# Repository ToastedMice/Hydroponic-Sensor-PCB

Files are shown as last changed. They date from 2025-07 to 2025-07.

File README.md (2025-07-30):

# Hydroponic-Sensor-PCB

A custom PCB designed for managing a smart hydroponic system. It will definitly need some modification as my use case is so specifc. It integrates components needed to automate water and nutrient delivery using peristaltic pumps and sensor feedback. I chose to use cheap sensors rather than good ones so that might need changing too.

## Features

- **5x N-Channel MOSFETs**  
  For switching 0-36v peristaltic pumps, I used NRF20L01's but it would probably be better for Rpi to get some logic level mosfets.

- **Sensor Support**  
  Has a port for pH sensor,EC, i2C USB port for a TSL2591 light sensor.

- **Microcontroller-Friendly**  
  Headers make it easy to connect additional i2c or 5v devices.

- **Compact Form Factor**  
  Layout for enclosure mounting and wire management. pH, EC, Battery could go inside a case

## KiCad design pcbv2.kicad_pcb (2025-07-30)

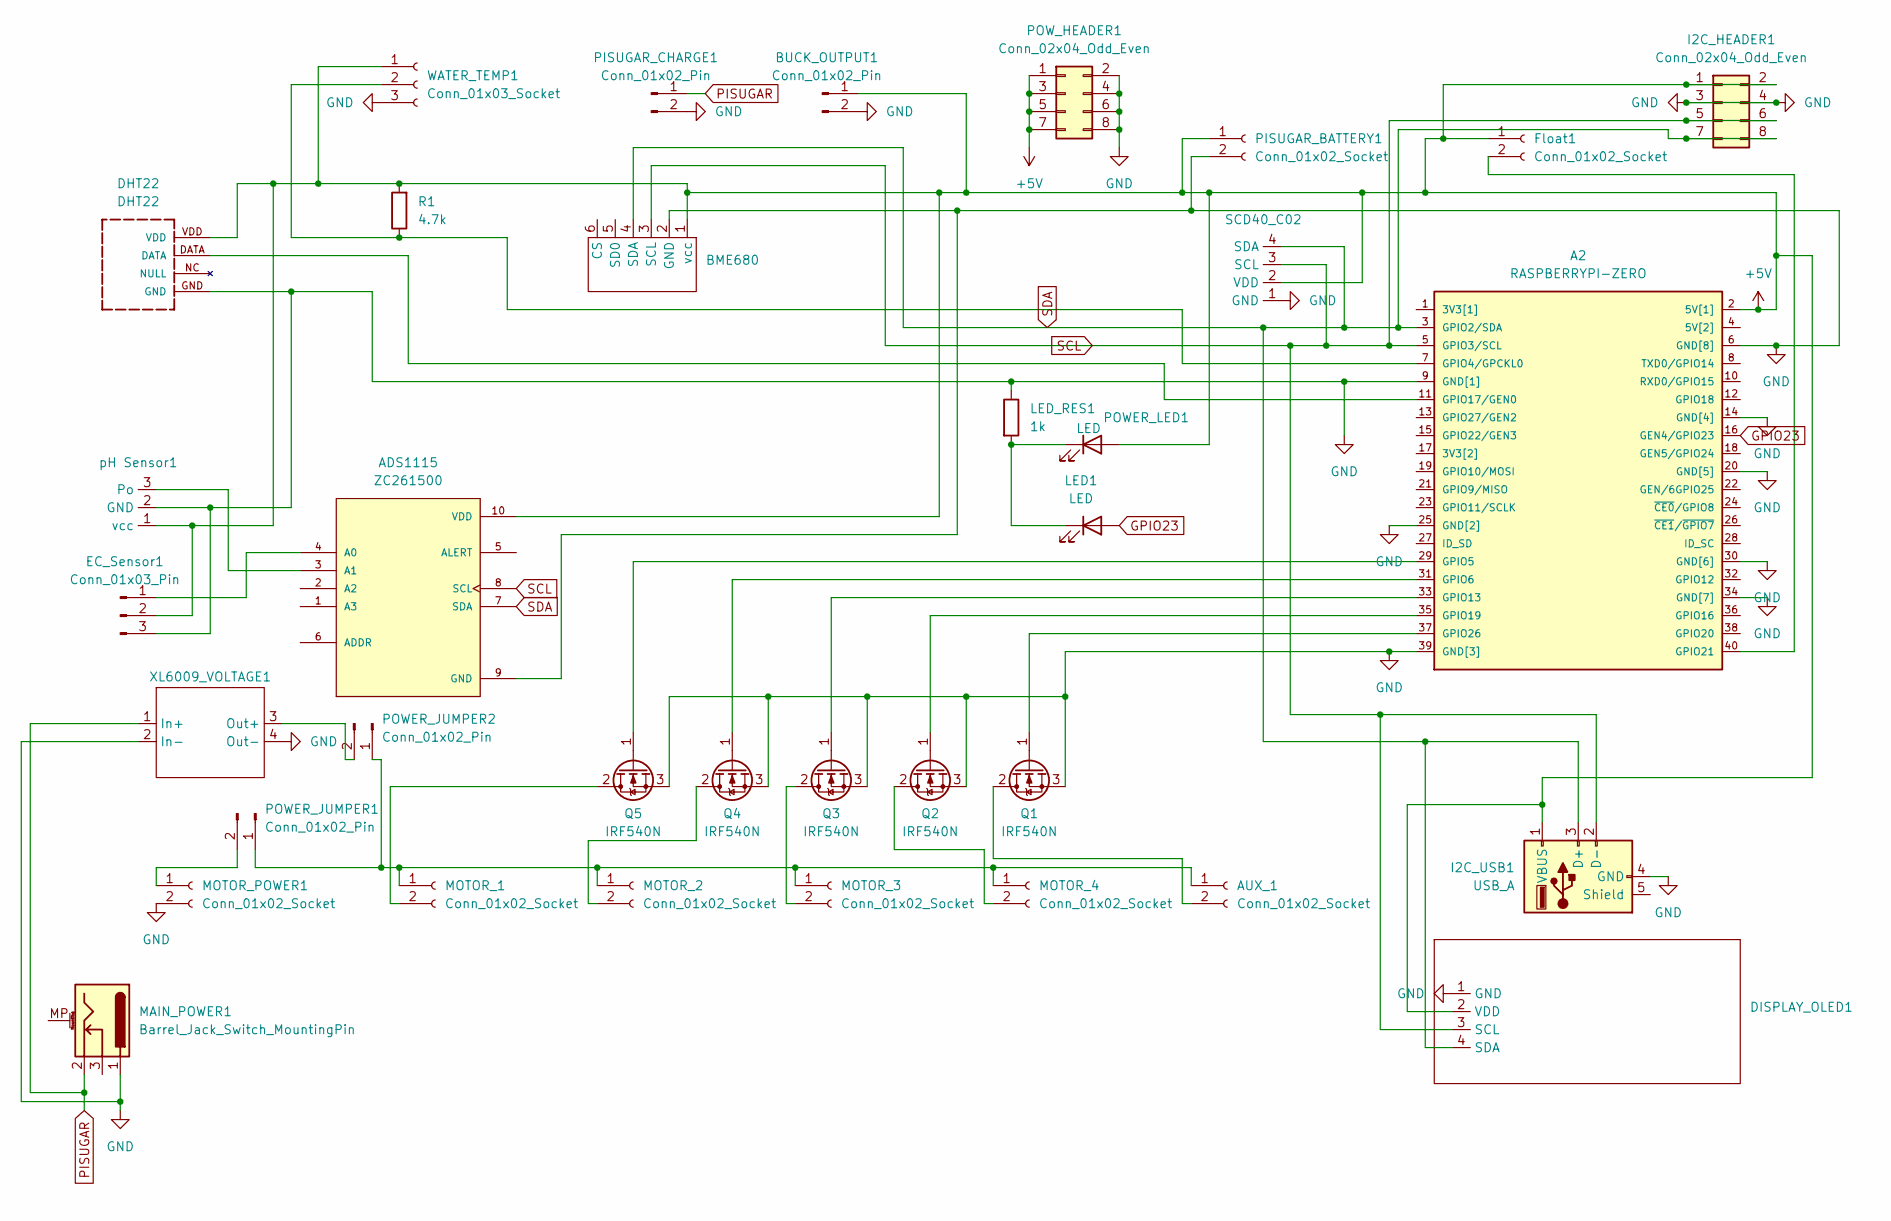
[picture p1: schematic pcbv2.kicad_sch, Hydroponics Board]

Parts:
A2: RASPBERRYPI-ZERO; RASPBERRYPI-ZERO_RPI-ZERO
ADS1115: ZC261500; MODULE_ZC261500; PARTREV NA
AUX_1: Conn_01x02_Socket; JST_XH_S2B-XH-A-1_1x02_P2.50mm_Horizontal
BME680: PinSocket_1x06_P2.54mm_Vertical
BUCK_OUTPUT1: Conn_01x02_Pin; JST_XH_S2B-XH-A-1_1x02_P2.50mm_Horizontal
DHT22: DHT22
DISPLAY_OLED1: JST_XH_S4B-XH-A-1_1x04_P2.50mm_Horizontal
EC_Sensor1: Conn_01x03_Pin; JST_XH_S3B-XH-A-1_1x03_P2.50mm_Horizontal
Float1: Conn_01x02_Socket; JST_XH_S2B-XH-A-1_1x02_P2.50mm_Horizontal
I2C_HEADER1: Conn_02x04_Odd_Even; PinHeader_2x04_P2.54mm_Vertical
I2C_USB1: USB_A; USB_A_Kycon_KUSBX-AS1N-B_Horizontal
LED1: LED; LED_D3.0mm
LED_RES1: 1k; R_Axial_DIN0207_L6.3mm_D2.5mm_P10.16mm_Horizontal
MAIN_POWER1: Barrel_Jack_Switch_MountingPin; BarrelJack_Horizontal
MOTOR_1, MOTOR_2, MOTOR_3, MOTOR_4: Conn_01x02_Socket; JST_XH_S2B-XH-A-1_1x02_P2.50mm_Horizontal
MOTOR_POWER1: Conn_01x02_Socket; JST_XH_S2B-XH-A-1_1x02_P2.50mm_Horizontal
PISUGAR_BATTERY1: Conn_01x02_Socket; JST_XH_S2B-XH-A-1_1x02_P2.50mm_Horizontal
PISUGAR_CHARGE1: Conn_01x02_Pin; JST_XH_S2B-XH-A-1_1x02_P2.50mm_Horizontal
POWER_JUMPER1, POWER_JUMPER2: Conn_01x02_Pin; PinHeader_1x02_P2.54mm_Vertical
POWER_LED1: LED; LED_D3.0mm
POW_HEADER1: Conn_02x04_Odd_Even; PinHeader_2x04_P2.54mm_Vertical
Q1, Q2, Q3, Q4, Q5: IRF540N; TO-220-3_Vertical
R1: 4.7k; R_Axial_DIN0207_L6.3mm_D2.5mm_P10.16mm_Horizontal
SCD40_C02: PinSocket_1x04_P2.54mm_Vertical
WATER_TEMP1: Conn_01x03_Socket; JST_XH_S3B-XH-A-1_1x03_P2.50mm_Horizontal
XL6009_VOLTAGE1: XL6009
pH Sensor1: JST_XH_S3B-XH-A-1_1x03_P2.50mm_Horizontal

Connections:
+5V: A2.2 (5V[1]), ADS1115.10 (VDD), BME680.1 (vcc), BUCK_OUTPUT1.1, DHT22.VDD, DISPLAY_OLED1.2 (VDD), EC_Sensor1.2, Float1.1, I2C_HEADER1.1, I2C_HEADER1.2, I2C_USB1.1 (VBUS), PISUGAR_BATTERY1.1, POWER_LED1.2 (A), POW_HEADER1.1, POW_HEADER1.3, POW_HEADER1.5, POW_HEADER1.7, R1.2, SCD40_C02.2 (VDD), WATER_TEMP1.1, pH Sensor1.1 (vcc)
GND: A2.6 (GND[8]), A2.9 (GND[1]), A2.14 (GND[4]), A2.20 (GND[5]), A2.25 (GND[2]), A2.30 (GND[6]), A2.34 (GND[7]), A2.39 (GND[3]), ADS1115.9 (GND), BME680.2 (GND), BUCK_OUTPUT1.2, DHT22.GND, DISPLAY_OLED1.1 (GND), EC_Sensor1.3, I2C_HEADER1.3, I2C_HEADER1.4, I2C_USB1.4 (GND), LED_RES1.1, MAIN_POWER1.1, MOTOR_POWER1.2, PISUGAR_BATTERY1.2, PISUGAR_CHARGE1.2, POW_HEADER1.2, POW_HEADER1.4, POW_HEADER1.6, POW_HEADER1.8, Q1.3 (S), Q2.3 (S), Q3.3 (S), Q4.3 (S), Q5.3 (S), SCD40_C02.1 (GND), WATER_TEMP1.3, XL6009_VOLTAGE1.2 (In-), XL6009_VOLTAGE1.4 (Out-), pH Sensor1.2 (GND)
GPIO23: A2.16 (GEN4/GPIO23), LED1.2 (A)
unnamed: A2.7 (GPIO4/GPCKL0), R1.1, WATER_TEMP1.2
unnamed: A2.29 (GPIO5), Q5.1 (G)
unnamed: A2.31 (GPIO6), Q4.1 (G)
unnamed: A2.33 (GPIO13), Q3.1 (G)
unnamed: A2.11 (GPIO17/GEN0), DHT22.DATA
unnamed: A2.35 (GPIO19), Q2.1 (G)
unnamed: A2.40 (GPIO21), Float1.2
unnamed: A2.37 (GPIO26), Q1.1 (G)
unnamed: ADS1115.4 (A0), EC_Sensor1.1
unnamed: ADS1115.3 (A1), pH Sensor1.3 (Po)
unnamed: AUX_1.1, MOTOR_1.1, MOTOR_2.1, MOTOR_3.1, MOTOR_4.1, POWER_JUMPER1.1, POWER_JUMPER2.1
unnamed: AUX_1.2, Q1.2 (D)
unnamed: LED1.1 (K), LED_RES1.2, POWER_LED1.1 (K)
unnamed: MOTOR_1.2, Q5.2 (D)
unnamed: MOTOR_2.2, Q4.2 (D)
unnamed: MOTOR_3.2, Q3.2 (D)
unnamed: MOTOR_4.2, Q2.2 (D)
unnamed: MOTOR_POWER1.1, POWER_JUMPER1.2
unnamed: POWER_JUMPER2.2, XL6009_VOLTAGE1.3 (Out+)
PISUGAR: MAIN_POWER1.2, PISUGAR_CHARGE1.1, XL6009_VOLTAGE1.1 (In+)
SCL: A2.5 (GPIO3/SCL), ADS1115.8 (SCL), BME680.3 (SCL), DISPLAY_OLED1.3 (SCL), I2C_HEADER1.5, I2C_HEADER1.6, I2C_USB1.2 (D-), SCD40_C02.3 (SCL)
SDA: A2.3 (GPIO2/SDA), ADS1115.7 (SDA), BME680.4 (SDA), DISPLAY_OLED1.4 (SDA), I2C_HEADER1.7, I2C_HEADER1.8, I2C_USB1.3 (D+), SCD40_C02.4 (SDA)

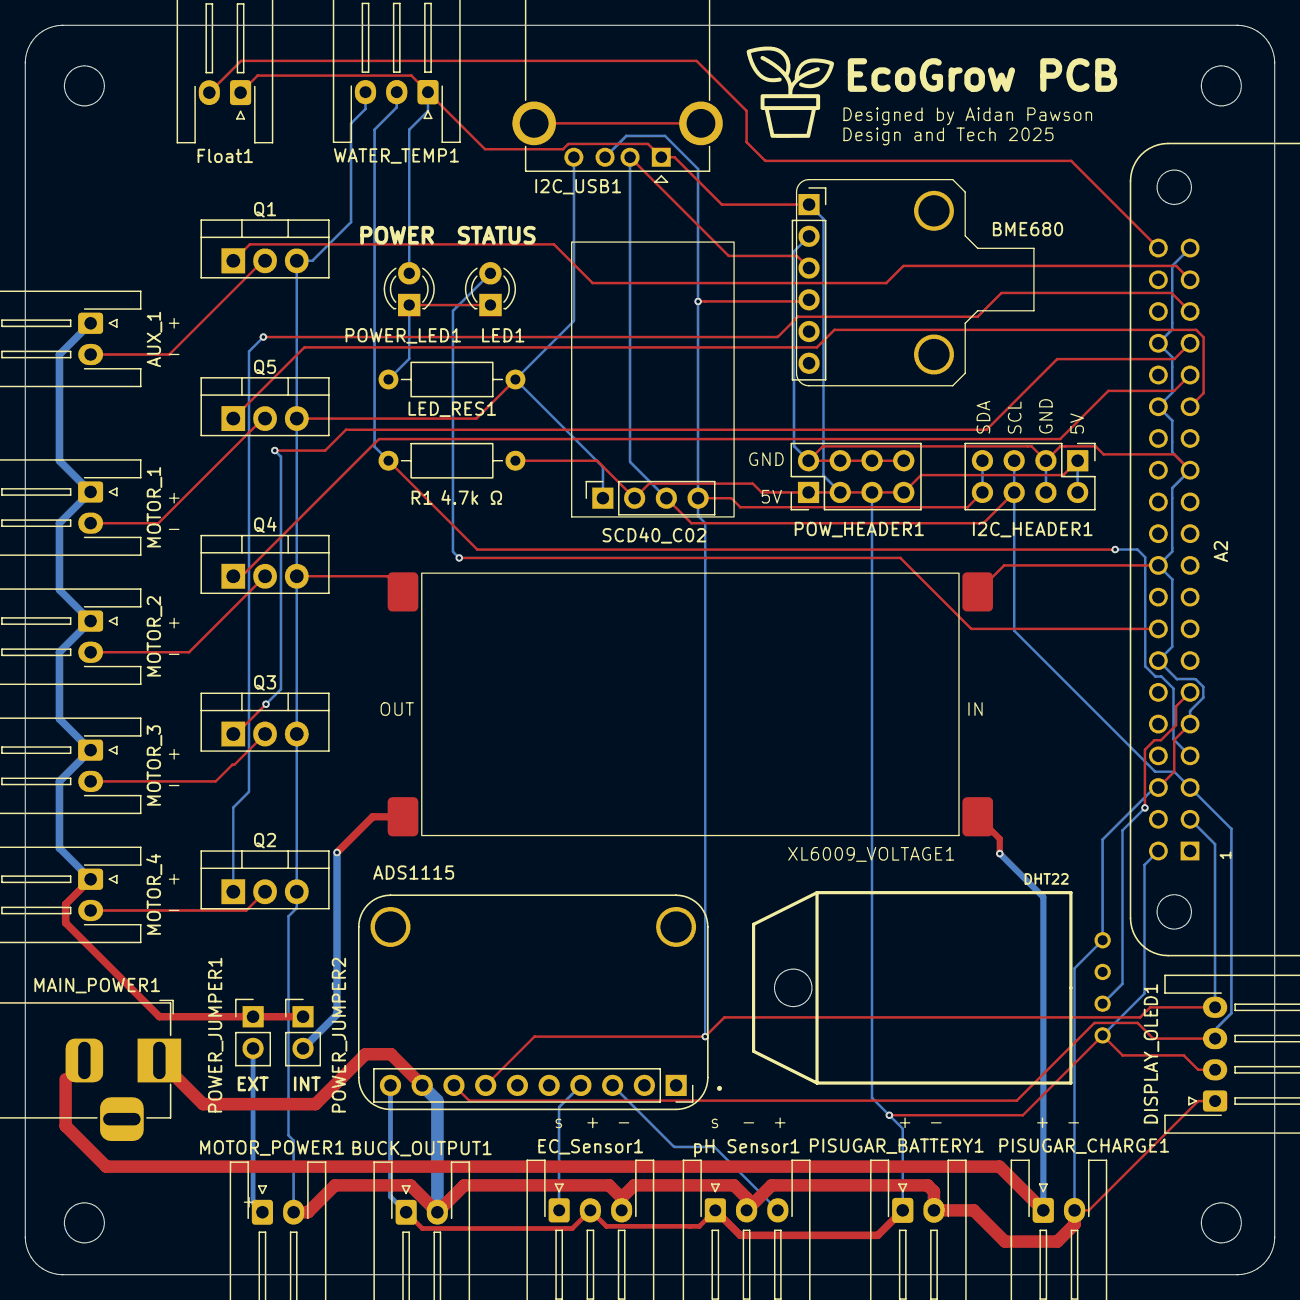
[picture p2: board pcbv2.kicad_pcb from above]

Board: 2 copper layers, 100.0 x 100.0 mm, 40 parts (1 on the bottom side), 25 nets.

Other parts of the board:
GDead_Plant: LOGO
M3_3.2mm_1, M3_3.2mm_2, M3_3.2mm_3, M3_3.2mm_4: MountingHole_3.2mm_M3
